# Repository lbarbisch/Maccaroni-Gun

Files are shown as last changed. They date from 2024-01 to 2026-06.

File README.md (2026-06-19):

# Macaroni-Gun
A fully 3D printed toy gun that shoots pasta.  
  
The idea for this came up when I stumbled upon this meme:  
  
pasta pistol meme

A friend an I took upon the challenge to construct a device that can "shoot" macaroni pasta.  

## V0
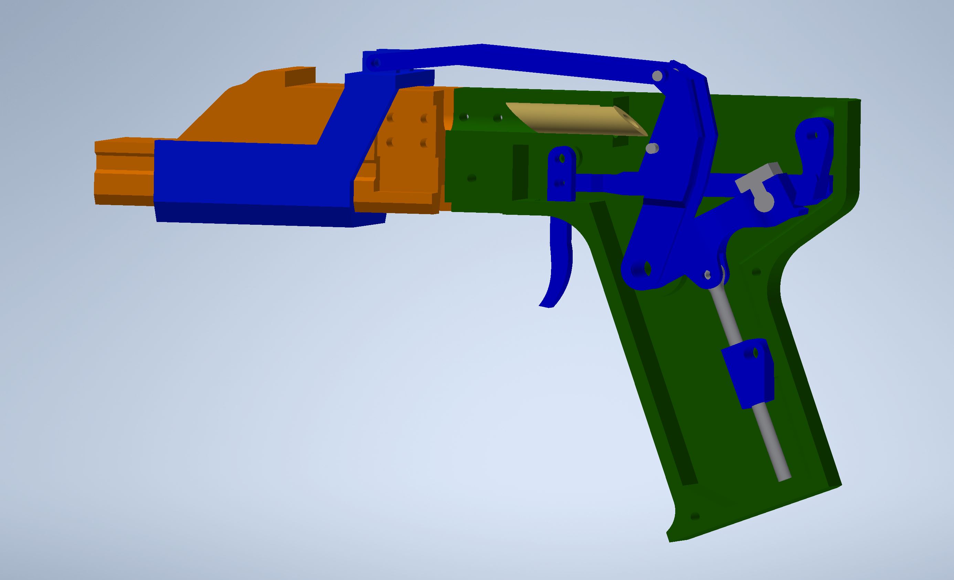
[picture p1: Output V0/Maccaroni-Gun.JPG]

This is the first version of a macaroni shooting device.
It is very bad and the major problem with this, that macaronis are brittle and this version works by hitting it with a hammer.  
So the macaroni shatters and the force isn't transferred well.

## V1 (work in progress)
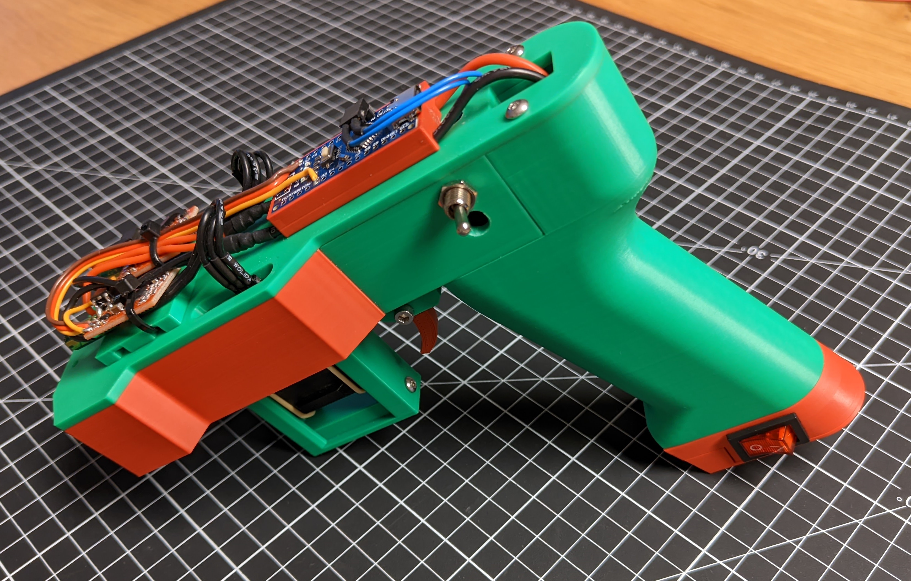
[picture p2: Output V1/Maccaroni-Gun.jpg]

This uses two flywheels made from TPU to softly grip the macaroni and accelerate it without shattering it.  
It and its internals are documented [here](https://barbisch.ch/projects/macaroni-gun).

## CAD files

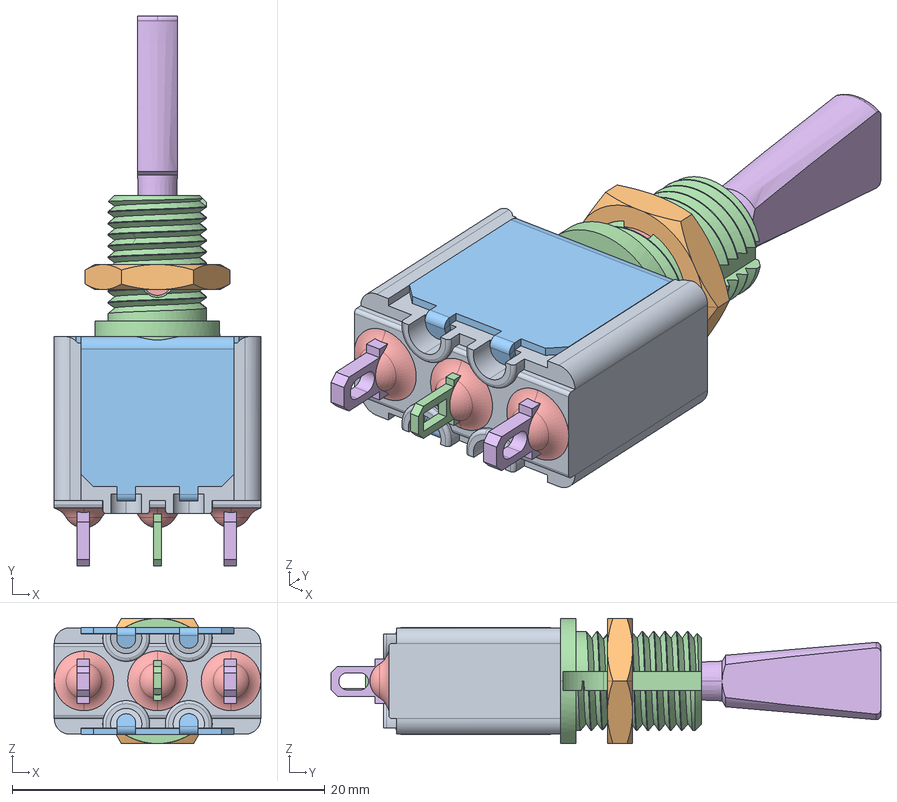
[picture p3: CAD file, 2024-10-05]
Inventor files/5632a9.stp
13.2 x 35.1 x 8.00 mm

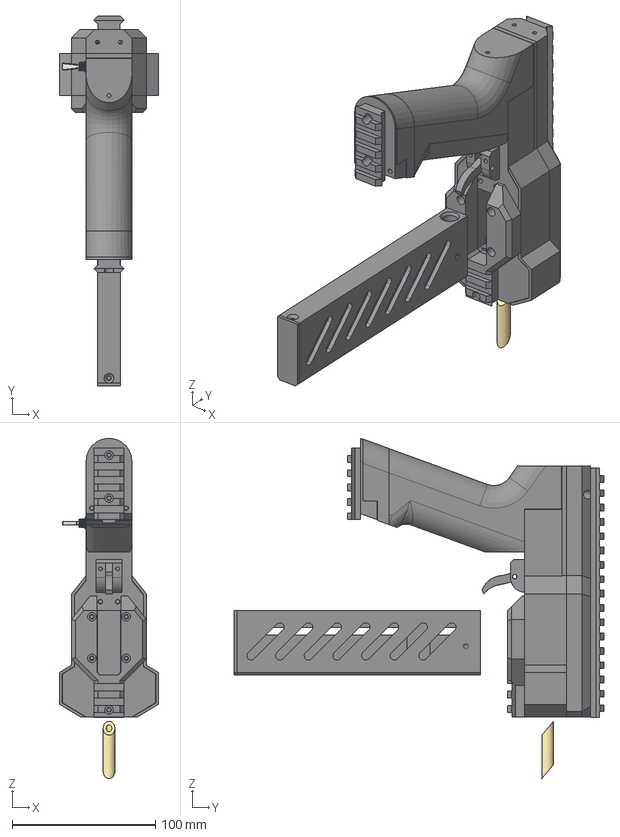
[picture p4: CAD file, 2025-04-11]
Output V1.1/Maccaronikanone.stp
69.0 x 258.3 x 237.4 mm
Griff_rechts
Maccaroni
Motor_holder
Motor_18mm x 2
Antriebsrad x 2
Magazin2
Magazin_Stössel
Griff_rechts_1
Hammer_Halter
Abzug
Hammer
Abzughalter
Top_Lid
Stiftleiste_Halter x 2
Stiftleiste_3Pin x 2
ESC_Halter
Arduinohalter
Hauptschalter
Ladesteckerhalter
5632a9
Deckel
Underrail
Picatinny Rail
Picatinny Rail_1
Magazin2_Stössel
Endschalter
Endschalterhalter1

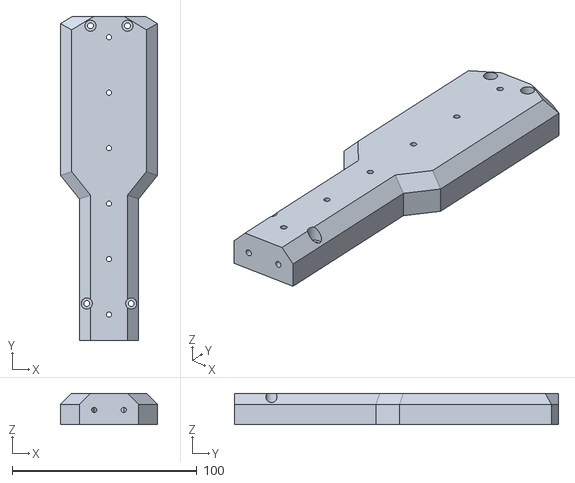
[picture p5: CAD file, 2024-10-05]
Output V1.1/Deckel.stl
52.4 x 175.2 x 17.0

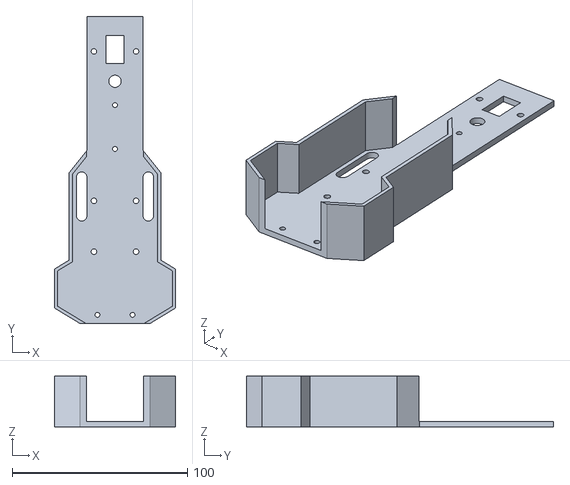
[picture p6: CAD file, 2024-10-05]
Output V1.1/Top_Lid.stl
69.0 x 175.2 x 29.0

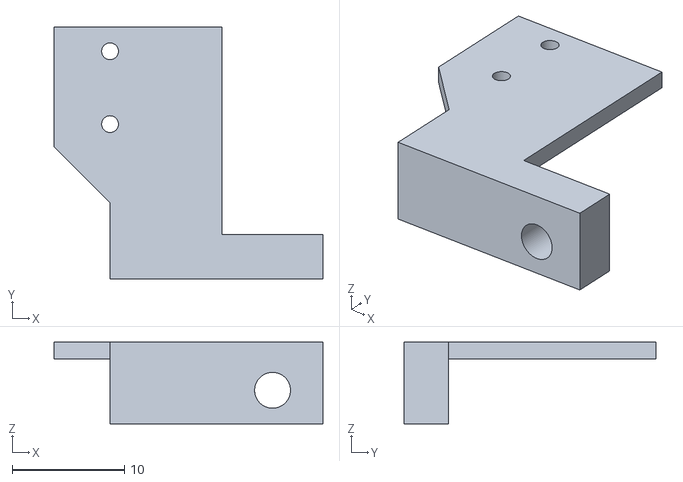
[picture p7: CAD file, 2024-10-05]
Output V1.1/Endschalterhalter.stl
24.0 x 22.5 x 7.30

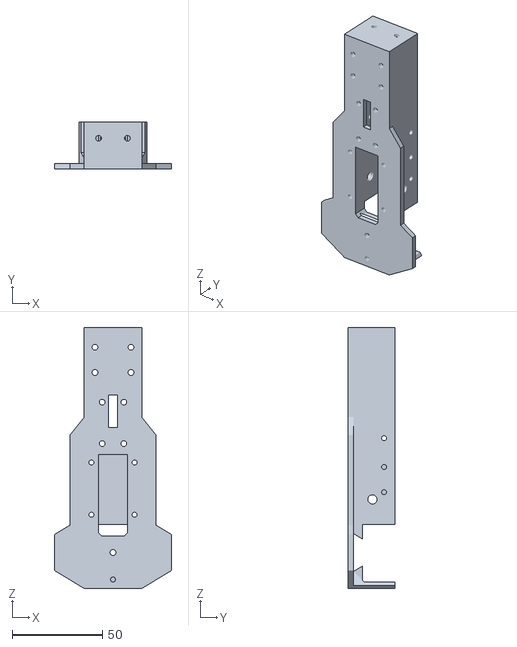
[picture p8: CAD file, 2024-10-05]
Output V1.1/Abzugsgehäuse.stl
65.0 x 26.0 x 145.0

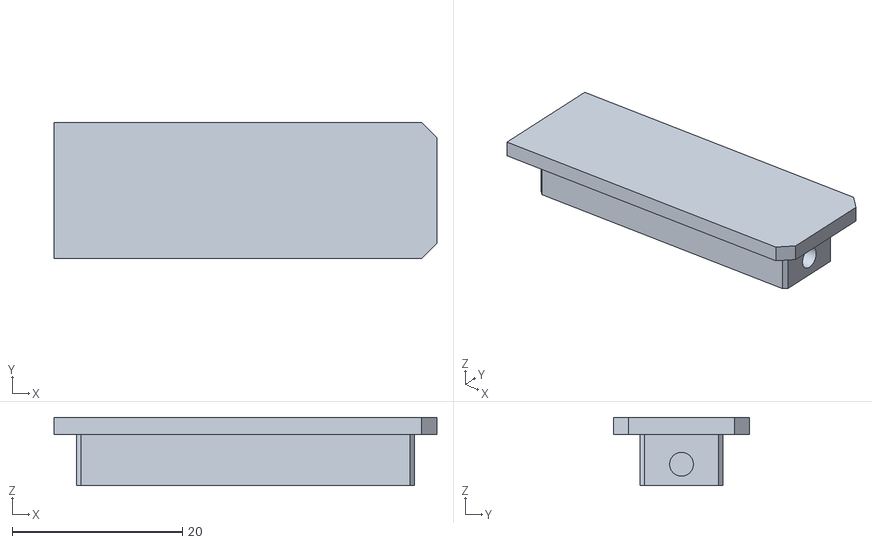
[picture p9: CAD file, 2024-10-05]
Output V1.1/Magazin2_Boden.stl
45.0 x 16.0 x 8.00

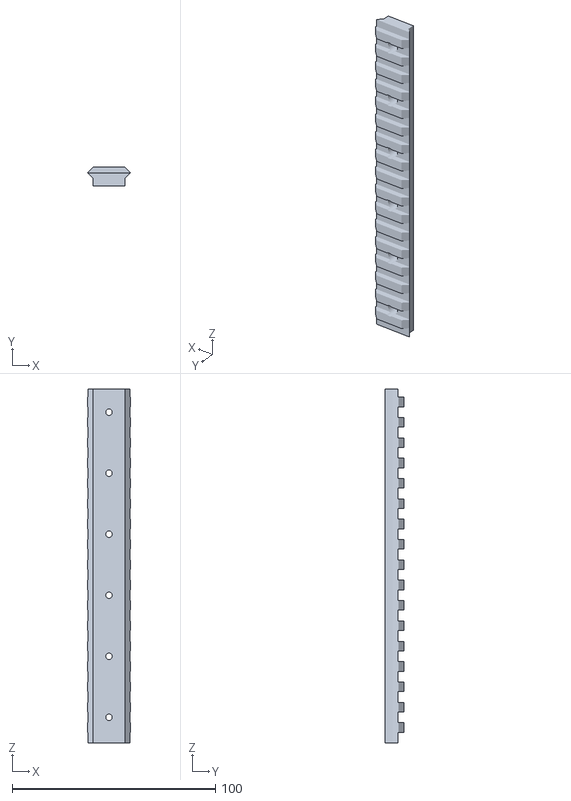
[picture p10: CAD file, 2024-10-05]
Output V1.1/Picatinny Rail.stl
21.2 x 9.32 x 174.0

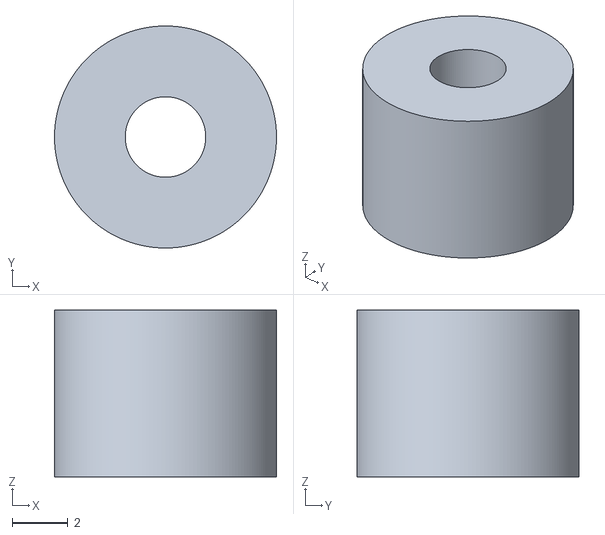
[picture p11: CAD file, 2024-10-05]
Output V1.1/Endschalter_betätiger.stl
8.00 x 8.00 x 6.00

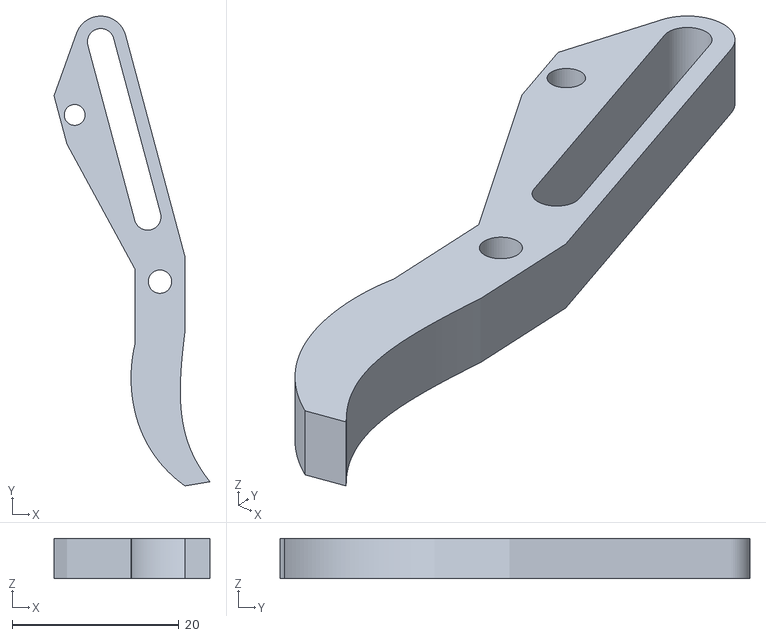
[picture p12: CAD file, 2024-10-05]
Output V1.1/Abzug2.stl
18.7 x 56.4 x 4.80

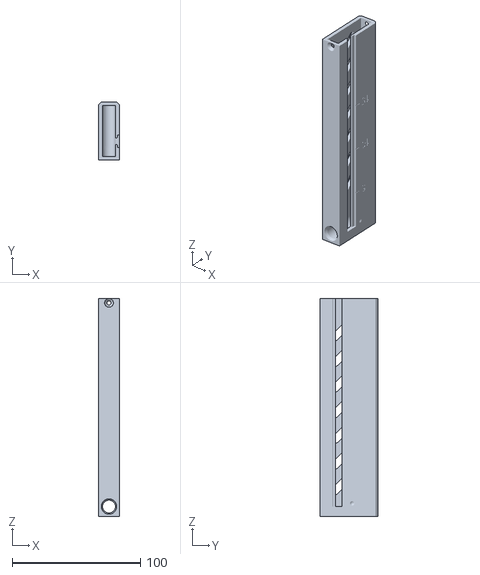
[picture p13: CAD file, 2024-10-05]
Output V1.1/Magazin2.stl
16.0 x 45.0 x 170.0

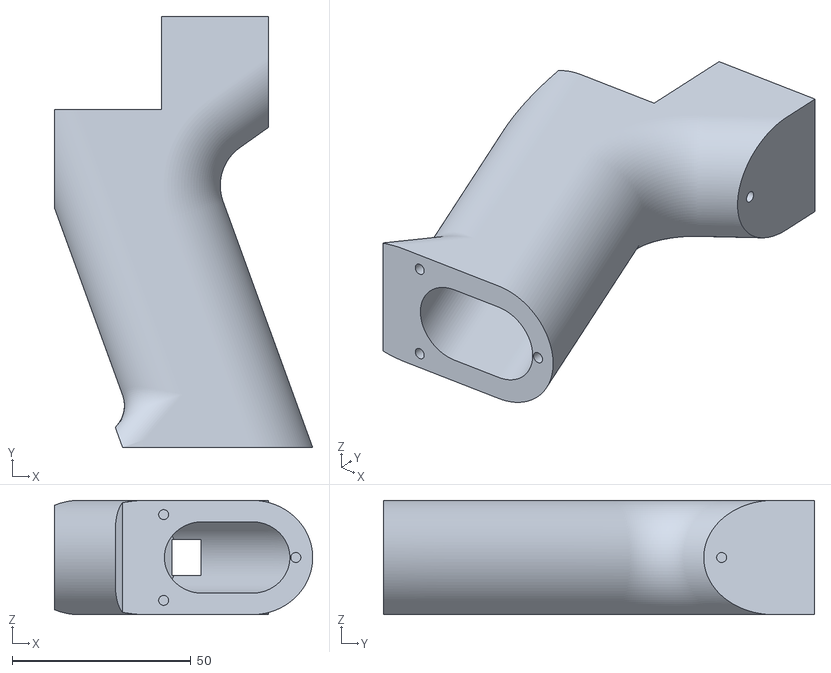
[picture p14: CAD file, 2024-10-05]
Output V1.1/Griff.stl
72.3 x 120.6 x 32.0

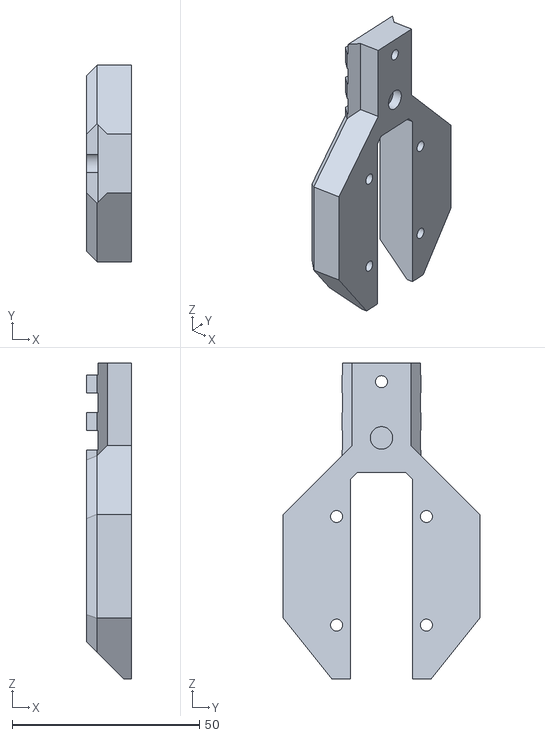
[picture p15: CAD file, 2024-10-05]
Output V1.1/Underrail.stl
12.0 x 52.5 x 84.4

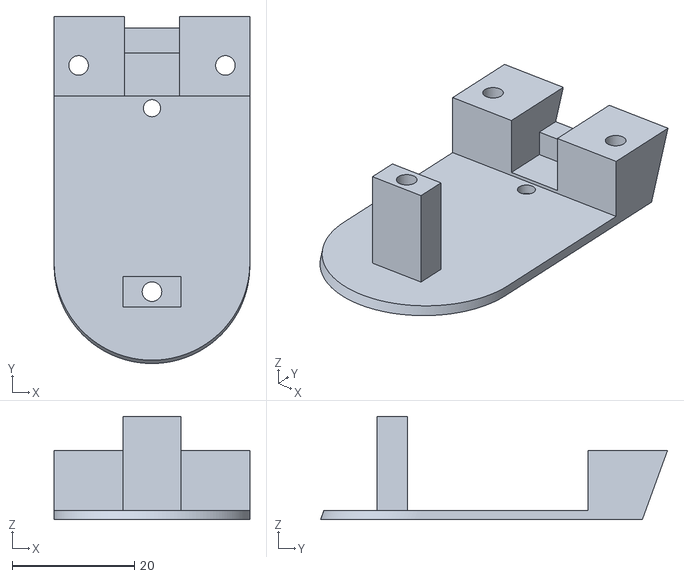
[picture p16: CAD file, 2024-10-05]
Output V1.1/Ladesteckerhalter.stl
32.0 x 56.7 x 16.9

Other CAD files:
Output V1.1/Magazin2_Stössel.stl
Output V1.1/Magazin.stl
Output V1.1/Picatinny Rail short.stl
Output V1.1/Hauptschalter.stl
Inventor files/5632a9.ipt
Inventor files/Abzug2.ipt
Inventor files/Abzughalter.ipt
Inventor files/Abzugsgehäuse.ipt
Inventor files/Antriebsrad.ipt
Inventor files/Arduinohalter.ipt
Inventor files/Deckel.ipt
Inventor files/ESC_Halter.ipt
Inventor files/Endschalter.ipt
Inventor files/Endschalter_betätiger.ipt
Inventor files/Endschalterhalter.ipt
Inventor files/Griff.ipt
Inventor files/Hammer2.ipt
Inventor files/Hammer_Halter.ipt
Inventor files/Hauptschalter.ipt
Inventor files/Ladesteckerhalter.ipt
Inventor files/Maccaron_Filter.ipt
Inventor files/Maccaroni.ipt
Inventor files/Maccaronikanone.iam
Inventor files/Magazin.ipt
Inventor files/Magazin2.ipt
Inventor files/Magazin2_Boden.ipt
Inventor files/Magazin2_Stössel.ipt
Inventor files/Magazin_Boden.ipt
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

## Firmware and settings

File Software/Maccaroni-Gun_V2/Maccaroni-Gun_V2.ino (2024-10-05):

#include <Servo.h>

Servo servo;
bool oldState = true;
const int servoPin = 2;
const int gndSwitchPin = A2;
const int switchPin = A1;
const int triggerPin = A4;
const int gndTriggerPin = A5;

const uint16_t power = 75;

void setup()
{
  Serial.begin(115200);
  Serial.println("Initializing Maccaroni-Gun");
  
  // prepare esc controll
  servo.attach(servoPin);
  servo.write(0); // set to 0
  delay(5000);    // let the esc initialize

  // prepare on/off switch
  pinMode(gndSwitchPin, OUTPUT);
  digitalWrite(gndSwitchPin, LOW);
  pinMode(gndTriggerPin, OUTPUT);
  digitalWrite(gndTriggerPin, LOW);
  pinMode(switchPin, INPUT_PULLUP);
  pinMode(triggerPin, INPUT_PULLUP);

  // init done
  Serial.println("Maccaroni-Gun Ready!");
}

void loop()
{
  if (digitalRead(switchPin) == false)    // check if safety is set to "DANGER"
  {
    // transition from off to on
    if ((oldState == false) && (digitalRead(triggerPin) == true))
    {
      Serial.println("enable motor");
      servo.write(power);
    }
    
    // transition from on to off (only for serial message)
    if ((oldState == true) && (digitalRead(triggerPin) == false))
    {
      Serial.println("off");
      servo.write(0);
    }
  }
  
  else      // safety switch is set to "SAFE"
  {
    servo.write(0);
  }
  
  oldState = digitalRead(triggerPin);
  delay(10);
}

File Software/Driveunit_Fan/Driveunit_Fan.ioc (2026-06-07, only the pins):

Mcu.UserName=STM32G030F6Px
PA0.GPIO_Label=ADC_Angle
PA0.Signal=ADC1_IN0
PA13.Signal=SYS_SWDIO
PA14-BOOT0.Signal=SYS_SWCLK
PA4.GPIO_Label=ADC_I_U
PA4.Signal=ADC1_IN4
PA5.GPIO_Label=ADC_I_V
PA5.Signal=ADC1_IN5
PA6.Signal=S_TIM16_CH1
PA7.GPIO_Label=ADC_VIN
PA7.Signal=ADC1_IN7
PA8.GPIO_Label=PWM_U
PA8.Signal=S_TIM1_CH1
PB3.GPIO_Label=PWM_W
PB3.Signal=S_TIM1_CH2
PB8.Signal=I2C1_SCL
PB9.Signal=I2C1_SDA

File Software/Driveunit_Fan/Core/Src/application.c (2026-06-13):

/*
 * application.c
 *
 *  Created on: Aug 6, 2024
 *      Author: Lukas
 */

#include "application.h"
#include "motorcontroller.h"

extern Controller moco;
extern volatile bool newData;

bool oldTriggerState = 1;
uint8_t stateMachine = 0;

int32_t targetA = 0;
int32_t targetB = -600;

#define SERVO_WAIT_MS  600
#define BLOCK_WAIT_MS  300
#define BLOCK_ABORT_MS 300

uint32_t timestamp = 0;

uint8_t rapidFireCount = 5;
uint8_t fireCount = 0;


void setup()
{
	HAL_TIM_PWM_Start(&htim16, TIM_CHANNEL_1);

	initMotorControl();

	moco.position = get_meas_angle();
	moco.old_angle = moco.position;
	moco.target = targetA;

	setnewData();
	update();

	while (moco.position > 1024) moco.position -= 2048;
	while (moco.position < -1024) moco.position += 2048;

	//setnewData();
	//update();
	enableMotor();
	//calibrateOffset(64);  // broken :/
}

void loop()
{
	// update control loop
	update();

	// detect falling edge of trigger button -> start pew
	if ((oldTriggerState == 1) && (HAL_GPIO_ReadPin(Trigger_GPIO_Port, Trigger_Pin) == 0) && (stateMachine == 0))
	{
		stateMachine = 1;
		timestamp = HAL_GetTick();
		enableFlywheels();
		fireCount = rapidFireCount;
	}

	// wait period for flywheels to spin up
	if (stateMachine == 1)
	{
		if ((HAL_GetTick() - timestamp) >= SERVO_WAIT_MS)
		{
			stateMachine = 2;
			timestamp = HAL_GetTick();
			moco.power_limit = 127;		// bump up power
			moco.target = targetA;
		}
	}

	// make sure motor is at starting position
	if (stateMachine == 2)
	{
		if ((abs(moco.position - targetA) < 10) || ((HAL_GetTick() - timestamp) >= BLOCK_ABORT_MS))
		{
			stateMachine = 3;
			timestamp = HAL_GetTick();
			moco.target = targetB;
		}
	}

	// move motor to positionB
	if (stateMachine == 3)
	{
		if ((abs(moco.position - targetB) < 10) || ((HAL_GetTick() - timestamp) >= BLOCK_ABORT_MS))
		{

			moco.target = targetA;
			fireCount--;

			if ((HAL_GetTick() - timestamp) >= BLOCK_ABORT_MS)
			{
				fireCount = 0;	// abort rapid fire when blocked
			}

			if (fireCount > 0)
			{
				// shoot once more
				stateMachine = 2;
			}
			else
			{
				// stop shooting
				stateMachine = 4;
			}
			timestamp = HAL_GetTick();
		}
	}

	// move motor back and after return disable flywheels
	if (stateMachine == 4)
	{
		if ((abs(moco.position - targetA) < 10) || ((HAL_GetTick() - timestamp) >= BLOCK_ABORT_MS))
		{
			disableFlywheels();
			stateMachine = 0;
			timestamp = HAL_GetTick();
			moco.power_limit = 32;		// reduce power for only holding position
		}
	}

	// logic to detect falling edge of button
	oldTriggerState = HAL_GPIO_ReadPin(Trigger_GPIO_Port, Trigger_Pin);
}

void enableFlywheels()
{
	htim16.Instance->CCR1 = 1300;
}

void disableFlywheels()
{
	htim16.Instance->CCR1 = 540;
}

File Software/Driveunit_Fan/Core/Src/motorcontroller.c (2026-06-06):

/*
 * motorcontroller.c
 *
 *  Created on: Apr 28, 2024
 *      Author: Lukas
 */

#include "motorcontroller.h"
#include "AS5600.h"

extern TIM_HandleTypeDef htim1;
extern ADC_HandleTypeDef hadc1;
extern I2C_HandleTypeDef hi2c1;

Controller moco;
volatile bool newData;

static inline uint16_t max(uint16_t value, uint16_t limit)
{
	if (value > limit)
		return limit;
	return value;
}

static inline float limit(float input, float min, float max)
{
	if (input > max)
		return max;
	if (input < min)
		return min;
	return input;
}

void initMotorControl()
{
	// initialize AS5600 encoder
	AS5600_init(&hi2c1, AS5600_CONF_L_HYST_OFF | AS5600_CONF_L_OUTS_AN | AS5600_CONF_L_PM_NOM | AS5600_CONF_L_PWMF_115, AS5600_CONF_H_FTH_SLOW | AS5600_CONF_H_SF_2x | AS5600_CONF_L_HYST_OFF);

	// enable PWM generation
	htim1.Instance->CCR1 = 0;
	htim1.Instance->CCR2 = 0;
	htim1.Instance->CCR4 = 0;
	HAL_TIM_PWM_Start(&htim1, TIM_CHANNEL_1);
	HAL_TIM_PWM_Start(&htim1, TIM_CHANNEL_2);
	HAL_TIM_PWM_Start(&htim1, TIM_CHANNEL_4);

	moco.mode = POSITION_MODE;
	moco.encoder_offset = 120;
	moco.angle_cw = (2048/7)/4;
	moco.angle_ccw = (2048/7)/4*3;
	moco.phase_offset1 = 0;			// 2048 / 7 / 3 * 0
	moco.phase_offset2 = 98;		// 2048 / 7 / 3 * 1
	moco.phase_offset3 = 195;		// 2048 / 7 / 3 * 2
	moco.power = 0;
	moco.power_limit = 127;
	moco.position = 0;
	moco.target = 0;
	moco.target_rpm = 800;
	moco.direction = 0;
	moco.meas_angle = 0;
	moco.old_angle = 0;
	moco.angle_error = 0;
	moco.Kp = 3.0f;
	moco.Ki = 0.015f;
	moco.Kd = 100.0f;
	moco.calibration = 0;
	moco.as5600_i2c_angle[0] = 0;
	moco.as5600_i2c_angle[1] = 0;
	moco.rpm = 0.0f;
	moco.rpm_oldPos = 0;
	moco.rpm_delayTimer = 0;
	moco.rpm_lowpass = 0.1;
}

void update()
{
	if (newData)
	{
		newData = false;
		if (moco.mode == TORQUE_MODE)
		{
			updateTorque();
		}
		else if (moco.mode == POSITION_MODE)
		{
			updatePosition();
		}
		else if (moco.mode == SPEED_MODE)
		{
			updateSpeed();
		}
	}
	else
	{
		HAL_I2C_Mem_Read_IT(&hi2c1, AS5600_I2C_ADDR, AS5600_REG_RAWANGLE, I2C_MEMADD_SIZE_8BIT, (uint8_t*)moco.as5600_i2c_angle, 2);
	}
}

void HAL_I2C_MemRxCpltCallback(I2C_HandleTypeDef *I2cHandle)
{
	__HAL_I2C_CLEAR_FLAG(I2cHandle, I2C_FLAG_RXNE);
	moco.meas_angle = (moco.as5600_i2c_angle[1] + (((uint16_t)moco.as5600_i2c_angle[0] & 0x0F) << 8))/2;
	newData = true;
}

void updatePosition()
{
	float proportional;
	float integral;
	static float differential;

	// determine direction and power
	moco.position_error = (moco.target - moco.position);

	proportional 	 = moco.Kp * moco.position_error;
	moco.integrator	 = limit(moco.integrator + moco.Ki * moco.position_error, -100.0f, 100.0f);
	integral 		 = moco.integrator + moco.Ki * moco.position_error;
	differential 	 = 0.9f * differential + 0.1f * moco.Kd * (moco.position_error - moco.old_position_error);

	float power = proportional + integral + differential;

	if (power > 0)
	{
		moco.direction = 0;
	}
	else
	{
		moco.direction = 1;
	}

	moco.power = max((uint16_t)abs(proportional + integral + differential), moco.power_limit);
	moco.old_position_error = moco.position_error;

	//moco.power = max(abs(moco.position_error), moco.power_limit);

	updateTorque(moco.meas_angle);
}

uint8_t delay = 0;

void updateSpeed()
{
	if (delay == 10)
	{
		float rpm_diff = moco.target_rpm - moco.rpm;
		moco.rpm_integrator = limit(rpm_diff/1000 + moco.rpm_integrator, 0, 127);
		moco.power = (uint8_t)limit(rpm_diff + moco.rpm_integrator, 0, 127);
		delay = 0;
	}
	delay += 1;
	updateTorque();
}

void updateTorque()
{
	// update global position and handle rotational overflow (2047.0 or 0.2047)
	moco.angle_error = (moco.meas_angle - moco.old_angle);

	// border setting must be chosen according the update rate and the max expected rpm
	const uint16_t border = 100;
	if (moco.old_angle < border)
	{
		// old_angle was slightly above 0
		if (moco.meas_angle > (2047-border))
		{
			// new angle was slightly below 2047
			// UNDERFLOW must have happened
			moco.position = moco.position - 2047;
		}
	}
	else if (moco.old_angle > (2048-border))
	{
		// old_angle was slightly below 2047
		if (moco.meas_angle < border)
		{
			// new angle was slightly above 0
			// OVERFLOW must have happened
			moco.position = moco.position + 2048;
		}
	}
	moco.position = moco.position + moco.angle_error;

	if (moco.rpm_delayTimer + 100 < HAL_GetTick())
	{
		moco.rpm = (1 - moco.rpm_lowpass)*moco.rpm + moco.rpm_lowpass*((60 * (moco.rpm_oldPos - moco.position)) / 2048 * 10);
		moco.rpm_delayTimer = HAL_GetTick();
		moco.rpm_oldPos = moco.position;
	}
	moco.old_angle = moco.meas_angle;

	if (moco.calibration)
	{
		if (moco.direction)
		{
			// thwo phases are switched !!
			htim1.Instance->CCR2 = ((sintab[(moco.meas_angle + moco.encoder_offset + moco.phase_offset1) % sintablen] * (uint16_t)moco.power) >> 7) + 1023;
			htim1.Instance->CCR1 = ((sintab[(moco.meas_angle + moco.encoder_offset + moco.phase_offset2) % sintablen] * (uint16_t)moco.power) >> 7) + 1023;
			htim1.Instance->CCR4 = ((sintab[(moco.meas_angle + moco.encoder_offset + moco.phase_offset3) % sintablen] * (uint16_t)moco.power) >> 7) + 1023;
		}
		else
		{
			// thwo phases are switched !!
			htim1.Instance->CCR2 = ((sintab[(moco.meas_angle + moco.encoder_offset + moco.phase_offset1) % sintablen] * (uint16_t)moco.power) >> 7) + 1023;
			htim1.Instance->CCR1 = ((sintab[(moco.meas_angle + moco.encoder_offset + moco.phase_offset2) % sintablen] * (uint16_t)moco.power) >> 7) + 1023;
			htim1.Instance->CCR4 = ((sintab[(moco.meas_angle + moco.encoder_offset + moco.phase_offset3) % sintablen] * (uint16_t)moco.power) >> 7) + 1023;
		}
	}
	else
	{
		if (moco.direction)
		{
			// thwo phases are switched !!
			htim1.Instance->CCR2 = ((sintab[(moco.meas_angle + moco.encoder_offset + moco.angle_cw + moco.phase_offset1) % sintablen] * (uint16_t)moco.power) >> 7) + 1023;
			htim1.Instance->CCR1 = ((sintab[(moco.meas_angle + moco.encoder_offset + moco.angle_cw + moco.phase_offset2) % sintablen] * (uint16_t)moco.power) >> 7) + 1023;
			htim1.Instance->CCR4 = ((sintab[(moco.meas_angle + moco.encoder_offset + moco.angle_cw + moco.phase_offset3) % sintablen] * (uint16_t)moco.power) >> 7) + 1023;
		}
		else
		{
			// thwo phases are switched !!
			htim1.Instance->CCR2 = ((sintab[(moco.meas_angle + moco.encoder_offset + moco.angle_ccw + moco.phase_offset1) % sintablen] * (uint16_t)moco.power) >> 7) + 1023;
			htim1.Instance->CCR1 = ((sintab[(moco.meas_angle + moco.encoder_offset + moco.angle_ccw + moco.phase_offset2) % sintablen] * (uint16_t)moco.power) >> 7) + 1023;
			htim1.Instance->CCR4 = ((sintab[(moco.meas_angle + moco.encoder_offset + moco.angle_ccw + moco.phase_offset3) % sintablen] * (uint16_t)moco.power) >> 7) + 1023;
		}
	}
}

void enableMotor()
{
	// enable all phases
	HAL_GPIO_WritePin(PWM_Enable_GPIO_Port, PWM_Enable_Pin, GPIO_PIN_SET);
}
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

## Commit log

2024-01-25 Initial commit of old version
    [2mmx30mm Welle.ipt, Abzug.ipt, Abzug.stl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]
2024-01-26 restructuring folders
    [2mmx30mm Welle.ipt, Abzug.ipt, Abzug.stl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]
2024-05-13 Flywheel pathfinder mockup (works)
    [Accelerator.iam, Antriebsrad.ipt, Flywheel_base.ipt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]
2024-05-16 Construction of V2 in progress Trigger mechanism mostly done TODO: Electronics bay Sights
    [Abzug.ipt, Abzug2.ipt, Abzughalter.ipt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]
2024-07-16 added version 1
    [Abzug2.ipt, Abzug2.stl, Abzughalter.ipt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]
2024-10-05 added changes for version V1.1 with extended magazine and picatinny rails
    [2mmx30mm Welle.ipt, 5632a9.ipt, 5632a9.stp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]
2025-04-11 updated coloring of model
    [Abzug2.ipt, Abzughalter.ipt, Abzugsgehäuse.ipt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]
2025-04-13 prototype software to add Driveunit to Maccaroni gun
2026-06-06 modified housing to fit motor and modified software for first tests
    [Abzugsgehäuse.ipt, Griff.ipt, Hammer2.ipt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]
2026-06-06 added servo output signal to pin 13 PA6 (ADC_I_W)
2026-06-07 added rapid fire logic and blockage mitigation timemout
    [Abzugsgehäuse.ipt, Maccaronikanone.iam]
2026-06-13 only increase motor current as required and added timeout for the motors when they are jammed and cant reach targets
    [application.c]
